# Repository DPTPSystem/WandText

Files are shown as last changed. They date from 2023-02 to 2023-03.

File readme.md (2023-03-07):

# Wand Text v2.10
* DPTP System - Wand Text v2.10
* Original version date: 2014-06-27.
* New version date: 2023-02-25.
* [neo-geo.hu](http://neo-geo.hu)
* PIC16F684, Thermal Fuse (acceleration switch assembly), MPLAB v8.91

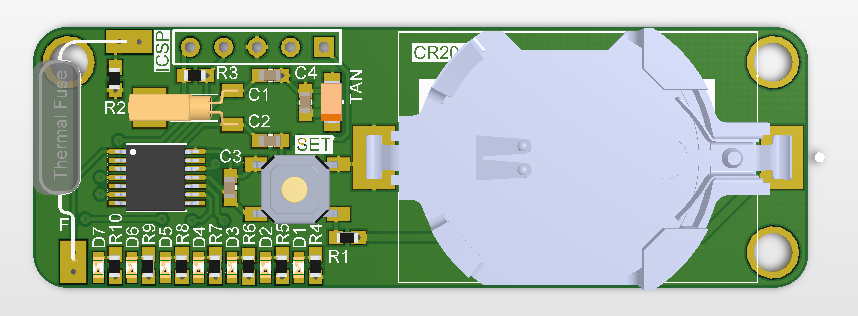
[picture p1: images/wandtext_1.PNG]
Wand Text v2.10


# Program működése
- A program működése rendkívül egyszerű. Egy Timer0-ás megszakítás fut, amely másodpercenként okoz megszakítást, ezért óra mérés is készíthető
a programban. Ez a másodperces megszakítás emel egy tétlenségi változót, majd, ha eléri a 30-at vagy is a 30mp tétlenséget, akkor
SLEEP üzemmódra vált vagy is aludni megy a kontroller. Gombnyomásra felébred az eszköz és folytatja a működését. A gomb megnyomására vált a szövegek közt,
az eszközt a megfelelő ütemben jobbra és ballra mozgatva kirajzolódik a LED játékából és annak a frissítéséből egy szöveg, amelyet 
előre meghatároztunk. Ezek a szövegek tetszőlegesen változtathatóak, de minden változáshoz ismételt programozásra van szükség, amely
az ICSP felületen megtörténhet egy PicKit2 vagy megfelelő programozó segítségével.

# Definiciók és változók
- definiciók:
- - `#define	LED1		RA0		// Értelem szerűen a LED-ek protjai`
- - `#define	LED2		RC0`
- - `#define	LED3		RC1`
- - `#define	LED4		RC2`
- - `#define	LED5		RC5`
- - `#define	LED6		RC3`
- - `#define	LED7		RC4		// Led7`
- - `#define OSZIDO		80		// Oszlopok frissítési ideje`
- - `#define	SZUNET		120		// Betűk közti szünet`
- - `#define Tetlen_mp	30		// 30mp tétlenség, SLEEP`
- - `#define GSZENZ		RA1		// Gyorsulási kapcsoló`
- - `#define GOMB		RA2		// Menü gomb, ébresztés`
- Változók:
- - `unsigned short int timer_count = 0;		// Timer számláló`
- - `unsigned char mp_count = 0;			// Másodperc számláló`

# Thermal Fuse
- Hő biztosítékból készítünk gyorsulás érzékelős kapcsolót. (helyettesíthető, ha van más ötleted, pl. xbox360 függőleges kapcsoló)
- videó a készítésről: [Kattints ide a videó megtekintéséhez!](https://youtu.be/Vj7QPg4JtCE)
- a hőbiztosítékot az egyik végénél, (jellemzően a csúcsosabb gyantás végénél) le kell vágni vagy a lábát levágva lecsiszolni, 
majd a belső részeket ki kell szedni. Ez után egy kisebb rugót és egy csapágygolyót a belsejébe kell helyezni, amelynek mozgása 
fogja a kapcsolást a biztosíték fala és a polus közt megteremteni. A levágott végénél ésszerűen egy nyákdarabot addig csiszolni,
ameddig az pontosan nem illik be a hengerbe, majd ennek közepére a lábat befúrni és a belső oldalán rögzíteni, hogy ne jöjjön ki.
A rögzítés nitteléssel vagy forrasztással is lehetséges. A lényeg, hogy az egyik lába a biztosítéknak VCC (ez logika kérdése is)
lesz, a másik lába viszont független (10K Ohm-os ellenállással le van húzva a terven) kell legyen, vagy is ez a lába fogja a kapcsolást 
érzékelni.

# További videók
- [DPTP System - WandClock 1.0](https://youtu.be/EMNUdDG5QfQ)
- [DPTP System - WandClock 2](https://youtu.be/C4ieYFhOSFA)
- [DPTP System - WandClock 3](https://youtu.be/fKSn2c8CGdg)
- [DPTP System - HandText 2.0](https://youtu.be/XQEPS1zDwPo)

# Újratervezés
-  A programot először 2014-ben majd ebben az évben történő fejlesztések, továbbfejlesztések történtek meg.
- 2023-ban újra elővettem és normális terveket készítettem az eszközhöz és publikáltam, mert kiváló tanuló projekt lehet belőle.
- Az előző változathoz képest csak a LED portok változtak az optimális tervezhetőség miatt.

# Javítások
- 2023-02-26. ICSP csatlakozó felületen hibásan volt bekötve a PGD (data) vonal, ezt LED7-es jelőlte. Utolsó módosítással ezt helyére
tettem, így LED1-re változott a jelőlés. 
- 2023-03-07. Polarítás váltás a GOMB esetében, negatív esetben érvényesül a program.
- - `if(!GOMB){`
- - `while(!GOMB);`

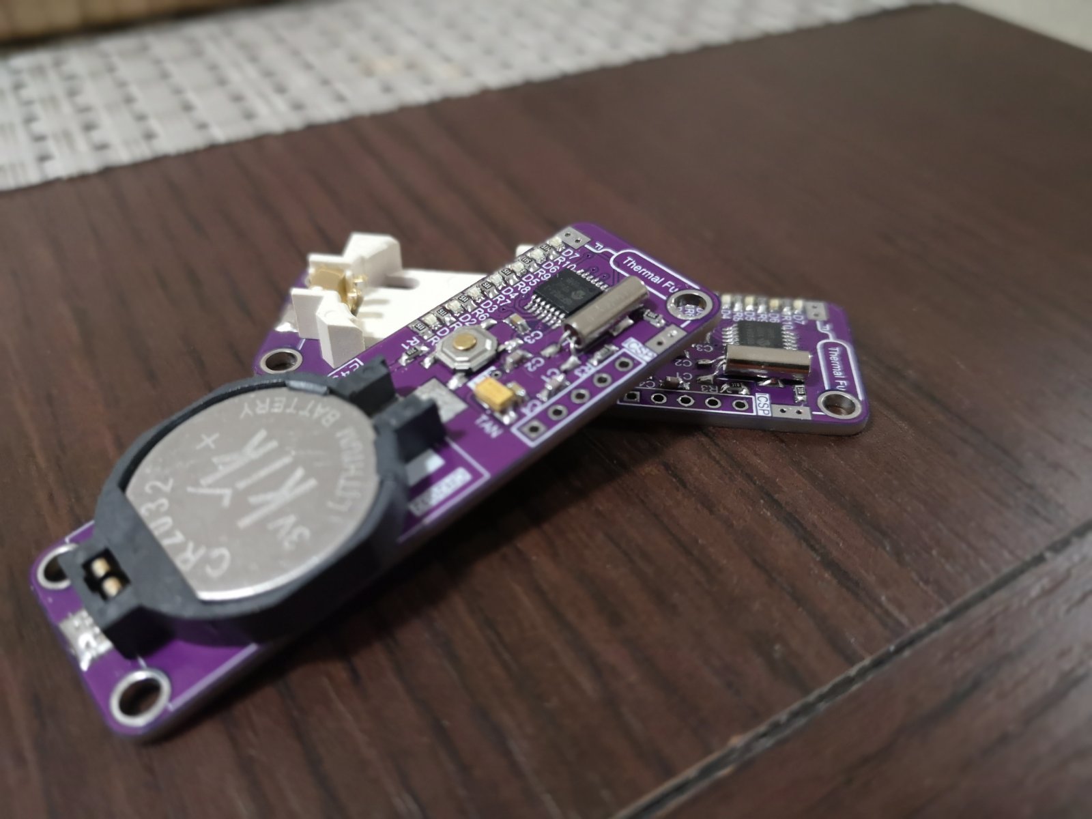
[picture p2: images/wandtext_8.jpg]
Wand Text v2.10


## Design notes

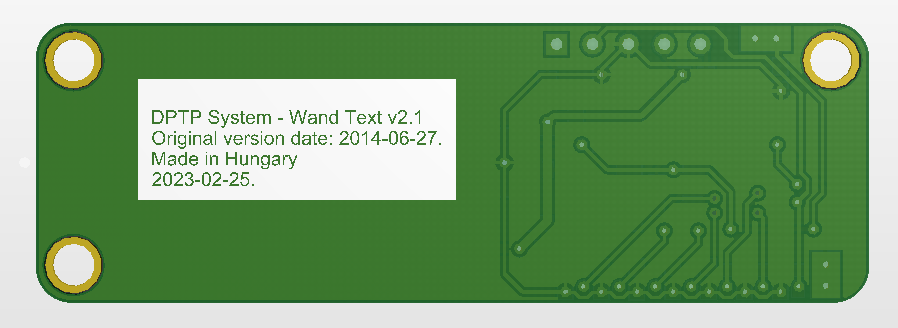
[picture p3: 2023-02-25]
images/wandtext_4.PNG

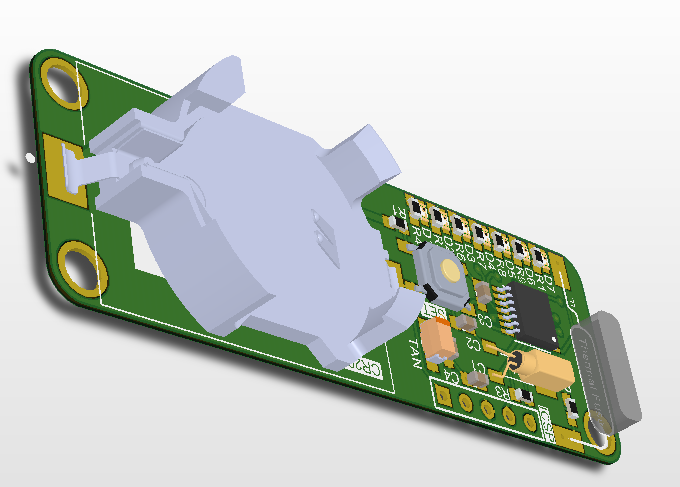
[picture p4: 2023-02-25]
images/wandtext_3.PNG

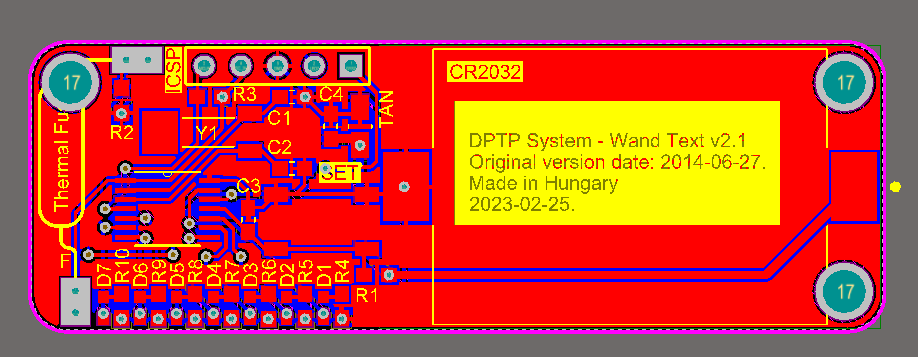
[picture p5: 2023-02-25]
images/wandtext_6.PNG

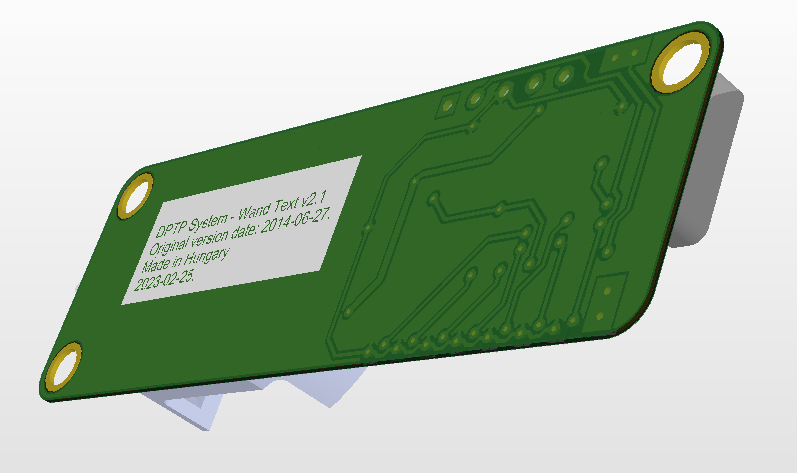
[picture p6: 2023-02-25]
images/wandtext_5.PNG

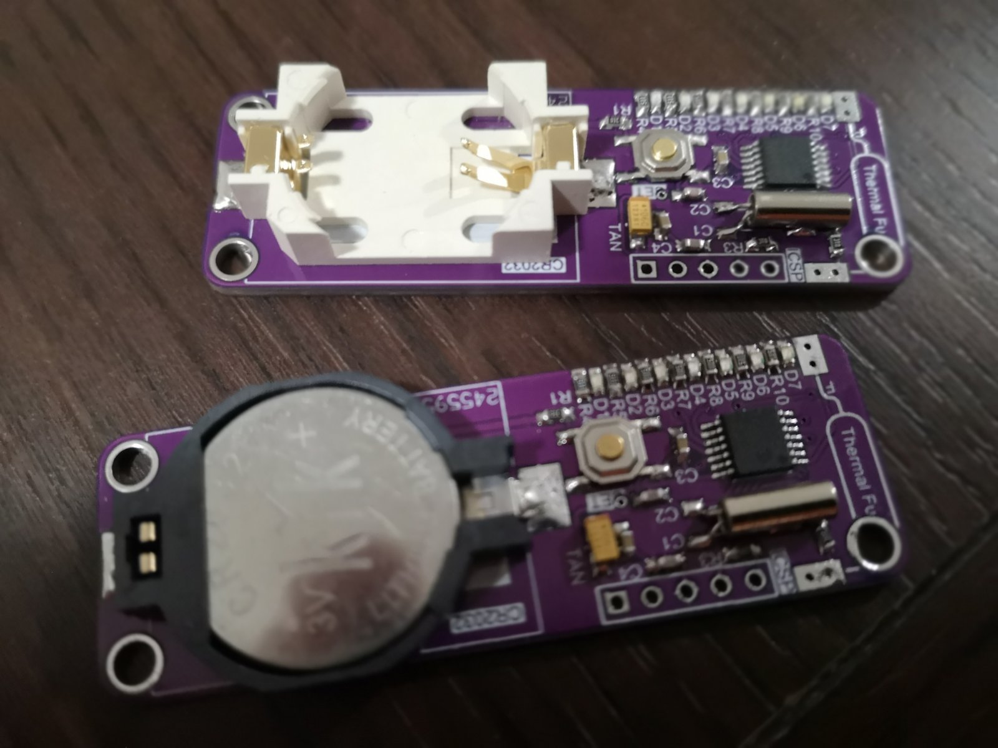
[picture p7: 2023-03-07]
images/wandtext_7.jpg

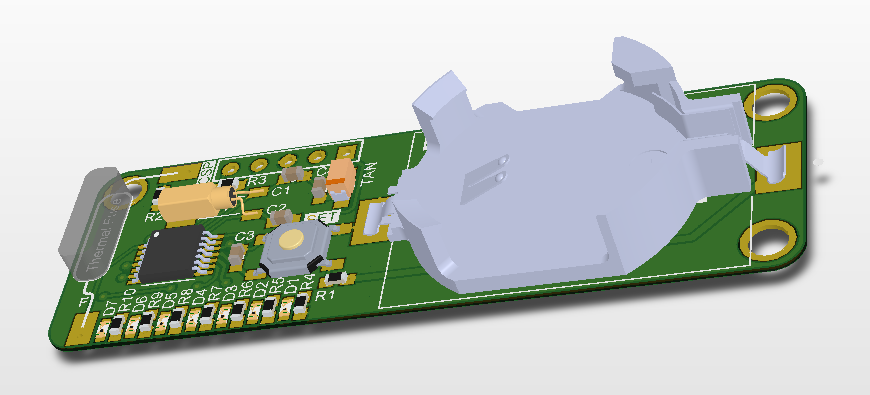
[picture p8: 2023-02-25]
images/wandtext_2.PNG

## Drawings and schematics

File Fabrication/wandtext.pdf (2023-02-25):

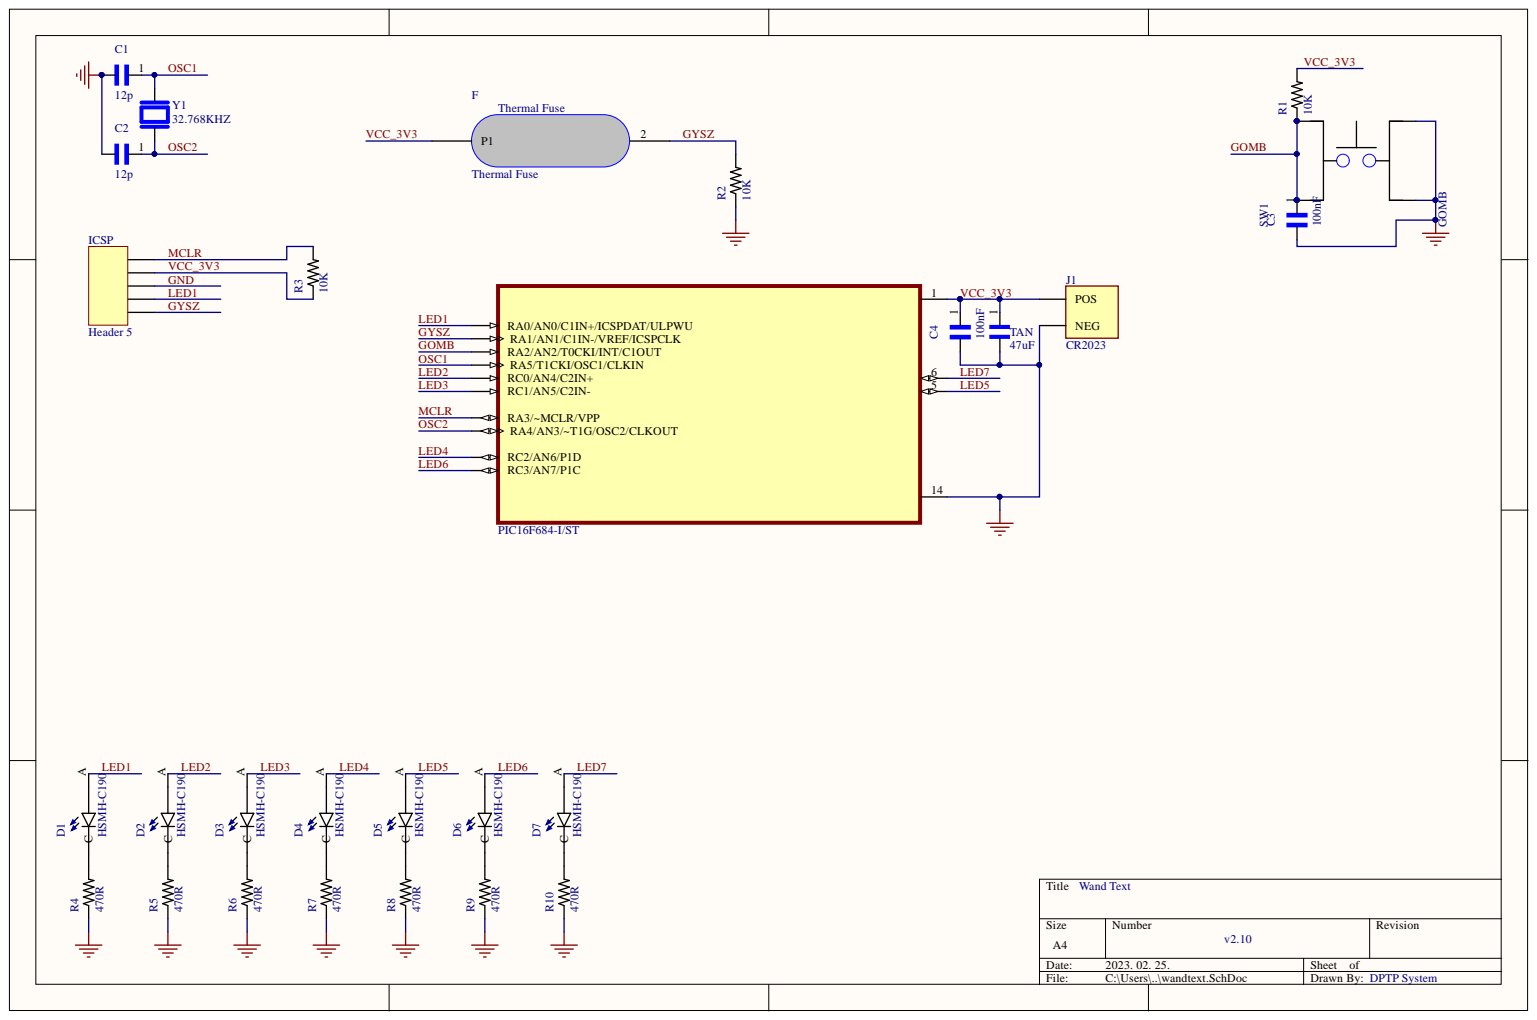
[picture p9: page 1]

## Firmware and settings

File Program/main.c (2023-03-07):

/* DPTP SYSTEM - WandClock 1.0
 * Dátum:   2014 júl. 9. Szerda
 * DPTP SYSTEM - WandClock 2.0
 * Dátum:   2014 júl. 27. Szerda
 * Email:	don_peter@freemail.hu
 * Processor: PIC16F684
 * Fórdító:  HI-TECH C for PIC10/12/16
 * DPTP System - Wand Text v2.10
 * Újra gondolva és gyártatva
 * Dátum:   2023 Feb. 24. Péntek
 */

#include <htc.h>			// 10,12,16-os PIC definiciók
#include <pic16f684.h>		// Mikrokontroller kiválasztása
#include <stdio.h>			// Alap függvények
#include <stdlib.h>
#include <string.h>
#include "header.h"			// Configurációs beállítások
#include "abc.c"

#define	LED1		RA0		// Led1
#define	LED2		RC0
#define	LED3		RC1
#define	LED4		RC2
#define	LED5		RC5
#define	LED6		RC3
#define	LED7		RC4		// Led7
#define OSZIDO		80		// Oszlopok frissítési ideje
#define	SZUNET		120		// Betük közti szünet
#define Tetlen_mp	30		// 30mp tétlenség
#define GSZENZ		RA1		// Gyorsulási kapcsoló
#define GOMB		RA2		// Menü gomb

// ---------------------------- //
//  Prototípusok			    //
// ---------------------------- //
void init();
void delay(short int ms);
unsigned char karakteratvalto(unsigned char karakter);
void karakter(unsigned char karakter, unsigned char irany);
void Wand_Text(char *pointer, unsigned char irany);
char *asd(char* in, char *out);

unsigned short int timer_count = 0;		// Timer számláló
unsigned char mp_count = 0;			// Másodperc számláló


// ---------------------------- //
//  Interrupt				    //
// ---------------------------- //
extern interrupt isr(void) {
	//TMR1H = 0x24; 
	//TMR1L = 0xF4;
	timer_count++;
			
	if(timer_count >= 1000){
		LED7 = 1;
		delay(100);
		LED7 = 0;
		timer_count = 0;
		mp_count++;
		if(mp_count >= Tetlen_mp){
			TRISA = 4;
			TRISC = 0;
			PORTA = 0;
			PORTC = 0;
			IOCA = 0b00000100;	// Gomb (RA2) beálítva megszakításra
			T0IE = 0;			// Timer0 interrupt kikapcsolva
			mp_count = 0;
			timer_count = 0;
			asm("SLEEP");
		}
	}
	
	if(RAIF == 1){
		RAIF = 0;
		IOCA = 0;		// IOCA kikapcsolva (RA2 Gomb megszakítás)
		RAIF = 0;		// A port interrupt flag törlése
		TRISA = 6;		// RA1 és RA2 bemenet
		TRISC = 0;		// C port kimenet
		PORTA = 0;		// A port alacsony szinten
		PORTC = 0;		// C port alacsony szinten
		T0IE = 1;		// Timer0 interrupt engedélyezve
		asm("NOP");
	}
	
	//TMR1IF = 0;
	//TMR2IF = 0;		// Timer megszakítás flag törlése
	T0IF = 0;
}

void main(void){
	unsigned char m = 0, i;
	short int gido = 0;

	init();
	
	while (1){
		
		// Multifunkciós gomb
		if(!GOMB){
			while(!GOMB);
			LED7 = 1;
			delay(500);
			LED7 = 0;
			delay(5000);
			LED7 = 1;
			delay(200);
			LED7 = 0;
			m++;
			delay(100);
			if(m==10) m=0;
			mp_count = 0;	// Tétlenség mérésének nullázása
		}
		
		if(GSZENZ == 1){
			if(m == 0){
				delay(2000);
				Wand_Text("PETI", '1');
				//Wand_Text("FERI", '1');
			}else if(m == 1){
				delay(2000);
				Wand_Text("ANDI", '1');
				//Wand_Text("MONI", '1');
			}else if(m == 2){
				delay(2000);
				Wand_Text("LACI", '1');
				//Wand_Text("NIKI", '1');
			}else if(m == 3){
				delay(2000);
				Wand_Text("MARTI", '1');
				//Wand_Text("KRISTOF", '1');
			}else if(m == 4){
				delay(2000); 
				Wand_Text("OPEL", '1');
				//Wand_Text("BMW M5", '1');
			}else if(m == 5){
				delay(2000);
				Wand_Text("BEACH", '1'); 
				//Wand_Text("ERDELY", '1'); 
			}else if(m == 6){
				delay(2000);
				Wand_Text("TIROL", '1');
				//Wand_Text("-F27-", '1');
			}else if(m == 7){
				delay(2000);
				Wand_Text("MUTER", '1');
			}else if(m == 8){
				delay(2000);
				Wand_Text("WAND C", '1');
				//Wand_Text("NYUNYI", '1');
			}else if(m == 9){
				delay(2000);
				Wand_Text("DPTP", '1');
			}
			mp_count = 0;	// Tétlenség mérésének nullázása
			//while(GSZENZ == 1);
		}
	
	}//while
	
}//main

// ---------------------------- //
//  Függvények				    //
// ---------------------------- //
void init(){

	ANSEL = 0;				// Minden láb digitális
	CMCON0 = 7;				// Comparator kikapcsolva
	CCP1CON = 0;			// Capt/Comp/PWM kikapcsolva	
	INTCON = 0;				// Összes interrupt láb kikapcsolva
	PEIE   = 1;				// Peripheral interrupt engedélyezése
	GIE    = 1;				// Globális interrupt engedélyezése
	OSCCON = 0b01110000;	// 8MHz-es órajel beállítva
	
	// 32.768KHz kristályhoz
	TMR0 = 249;				// Timer0
	OPTION = 2;				// 8-es osztás
	T0IE = 1;				// Interrupt engedélyezve
	
	
	// Timer1 ((2000000/4)/8) = 62500 == 1mp
	/*T1CON = 0b00110001;	//(FOSC/4)/8
	TMR1H = 0x24; 
	TMR1L = 0xF4;
	TMR1IE = 1;*/

	// Timer 2 8MHz
	/*PR2 = 250 ;
	T2CON = 0b00111111;		// 8millió / 16elõ és 8 utóosztás == 62.500/250 == 250 == 50lefutás ~1mp
	TMR2IE = 1;*/
	
	// Sleep üzemmód beállítása
	IOCA = 0;				// ICOA kikapcsolva
	RAIF = 0;				// A prot interrupt flag nullázása
	RAIE = 1;				// A port interrupt engedélyezése
	TRISC = 0;				// kimenet
	TRISA = 6;				// RA1 Gyorsulási szenzort és RA2 Menü gomb bemenet többi kimenet
	PCON = 0b0010000;		// Ultra alacsony energia engedélyezve (wake-up)
	PORTC = 0;				// C port alacsony szinten
	PORTA = 0;				// A port alacsony szinten
}

 //---- késleltetõ függvény
 void delay(short int ms){
	short int i;
	for(i=0; i<=ms; i++);
}

unsigned char karakteratvalto(unsigned char karakter){
    static char chars[40] = "ABCDEFGHIJKLMNOPQRSTUVWXYZ0123456789-:. ";
    unsigned char i, result;
    for(i=0; i<40; i++){
        if(karakter == chars[i]){
            result = i;
            break;
        }
    }
    return result;
}

void karakter(unsigned char karakter, unsigned char irany){
    unsigned char i;
    unsigned char mask;
    for(i=0; i<5; i++){
        mask = (irany=='0') ? i : 4-i;
		LED1 = ABC[karakter][6]>>mask;
		LED2 = ABC[karakter][5]>>mask;
		LED3 = ABC[karakter][4]>>mask;
		LED4 = ABC[karakter][3]>>mask;
		LED5 = ABC[karakter][2]>>mask;
		LED6 = ABC[karakter][1]>>mask;
		LED7 = ABC[karakter][0]>>mask;
        delay(OSZIDO);
		LED1 = LED2 = LED3 = LED4 = LED5 = LED6 = LED7 = 0;
		delay(OSZIDO);
    }
	delay(SZUNET);
}

void Wand_Text(char *pointer, unsigned char irany){
    unsigned char i=0;
    while(pointer[i]){
        karakter(karakteratvalto(pointer[i]), irany);
        i++;
    }
}

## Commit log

2023-02-25 Update 2023-02-25.
    ICSP fix
    [handtext.GBL, handtext.GTL]
2023-02-25 Update 2023-02-25.
    [handtext.GTL]
